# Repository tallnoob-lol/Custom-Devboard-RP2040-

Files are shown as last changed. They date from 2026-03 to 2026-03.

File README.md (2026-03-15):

# Custom-Devboard-RP2040-
Custom development board using the RP2040 microcontroller with 20 GPIO pins, 4 ADC pins, 2 user-controlled LED, 1 user button, etc.

## Why this?
I started this project, because I wanted to learn more about KiCAD. Also, I wanted a DevBoard that i could easily prototype with. As, most of the DevBoards online had some quirks like random GPIO arrangement or doesnt have any means of displaying a output on the board itself. So, I built this and it really helped in many ways.

## Features
- RP2040 microcontroller at 133MHz
- USB Type-C connector
- max 600mA power draw
- Boot and reset buttons
- Power & 2 User LED
- GPIO header pins
- Debug connector
- Bootsel, Reset & User Buttons

## Hardware Design
The hardware design will include:
- Power by AP2112K-3.3 linear LDO regulator
- 16mB External QSPI flash from W25Q16JVZPIQ TR
- USB-C interface for programming and power
- Clock source: 12MHz Crystal

## Pictures
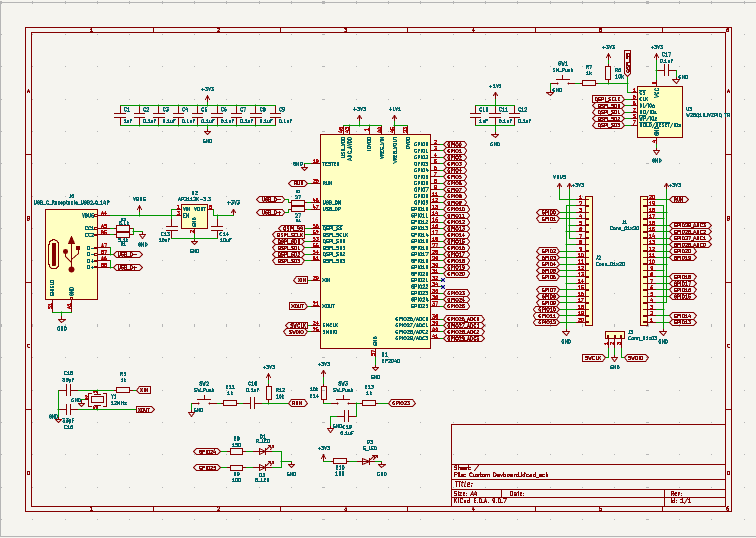
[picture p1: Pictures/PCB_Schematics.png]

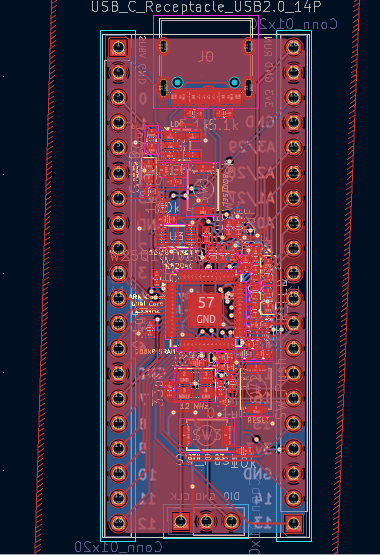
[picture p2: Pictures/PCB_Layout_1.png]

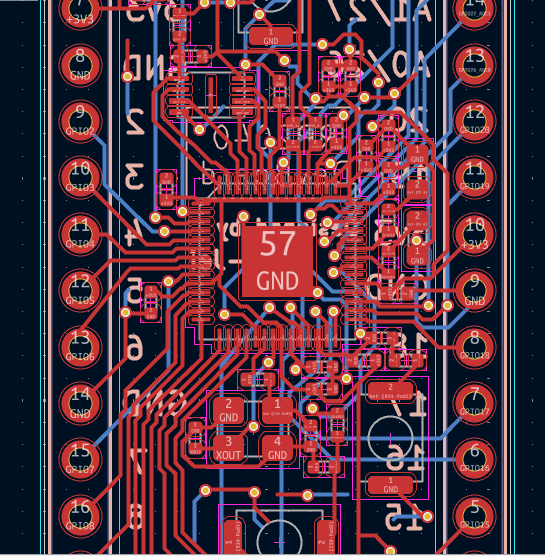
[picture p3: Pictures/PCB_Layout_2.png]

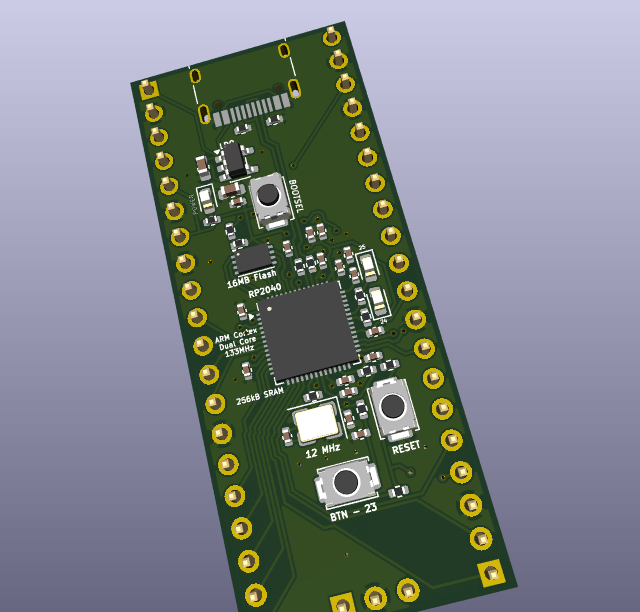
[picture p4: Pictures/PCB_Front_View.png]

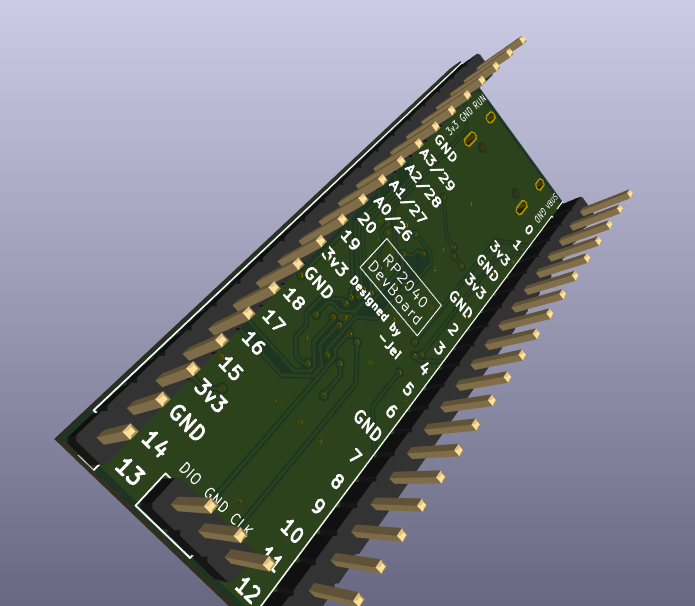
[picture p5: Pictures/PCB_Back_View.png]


## Future Improvements
- Add Li-ion compatibility
- On-Board tiny OLED display
- Improved portability for prototyping

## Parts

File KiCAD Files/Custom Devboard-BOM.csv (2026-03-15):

Id | Designator | Footprint | Quantity | Designation | Supplier and ref
1 | U3 | Winbond_USON-8-1EP_3x2mm_P0.5mm_EP0.2x1.6mm | 1 | W25Q16JVZPIQ TR
2 | R13,R5,R7,R11 | R_0402_1005Metric | 4 | 1k
3 | C10,C1 | C_0402_1005Metric | 2 | 1uF
4 | C19,C9,C6,C17,C12,C11,C18,C2,C5,C4,C7,C8,C3 | C_0402_1005Metric | 13 | 0.1uF
5 | U2 | SOT-23-5 | 1 | AP2112K-3.3
6 | D1 | LED_0603_1608Metric | 1 | R_LED
7 | U1 | QFN-56-1EP_7x7mm_P0.4mm_EP3.2x3.2mm | 1 | RP2040
8 | C15,C16 | C_0402_1005Metric | 2 | 33pF
9 | Y1 | Crystal_SMD_3225-4Pin_3.2x2.5mm | 1 | 12MHz
10 | R1,R2 | R_0402_1005Metric | 2 | 5.1k
11 | D3 | LED_0603_1608Metric | 1 | G_LED
12 | R4,R3 | R_0402_1005Metric | 2 | 27
13 | R14,R6,R12 | R_0402_1005Metric | 3 | 10k
14 | D2 | LED_0603_1608Metric | 1 | B_LED
15 | SW3,SW1,SW2 | SW_Push_SPST_NO_Alps_SKRK | 3 | SW_Push
16 | C13,C14 | C_0603_1608Metric | 2 | 10uF
17 | R9,R10 | R_0402_1005Metric | 2 | 100
18 | R8 | R_0402_1005Metric | 1 | 150
19 | J0 | USB_C_Receptacle_HRO_TYPE-C-31-M-12 | 1 | USB_C_Receptacle_USB2.0_14P
20 | J2,J1 | PinHeader_1x20_P2.54mm_Vertical | 2 | Conn_01x20
21 | J3 | PinHeader_1x03_P2.54mm_Vertical | 1 | Conn_01x03

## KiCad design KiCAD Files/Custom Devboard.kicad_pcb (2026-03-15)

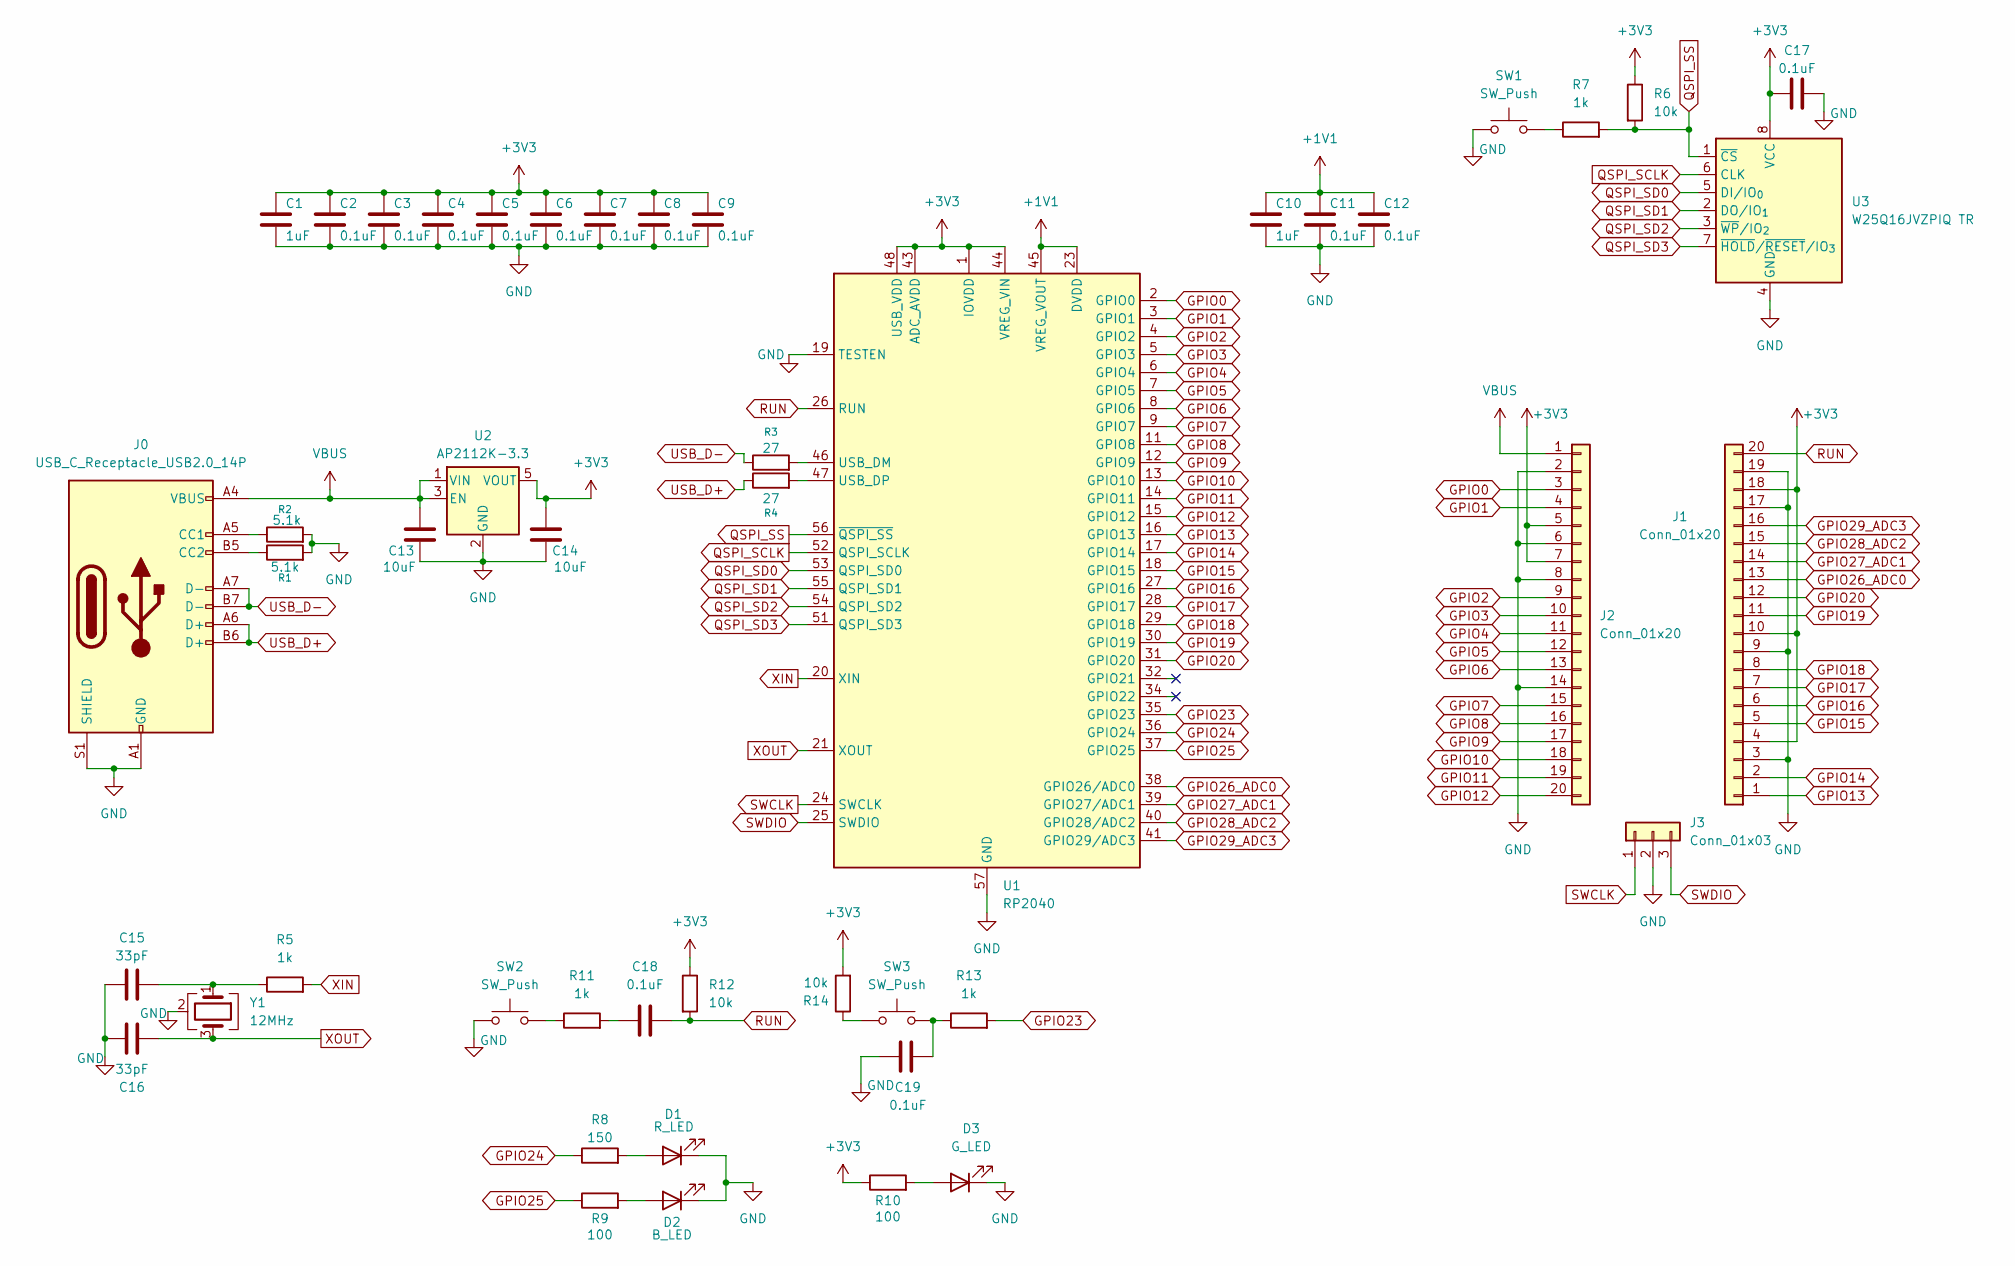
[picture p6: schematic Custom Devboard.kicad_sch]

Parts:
C1, C10: 1uF; C_0402_1005Metric
C2, C3, C4, C5, C6, C7, C8, C9, C11, C12, C17, C18, C19: 0.1uF; C_0402_1005Metric
C13, C14: 10uF; C_0603_1608Metric
C15, C16: 33pF; C_0402_1005Metric
D1: R_LED; LED_0603_1608Metric
D2: B_LED; LED_0603_1608Metric
D3: G_LED; LED_0603_1608Metric
J0: USB_C_Receptacle_USB2.0_14P; USB_C_Receptacle_HRO_TYPE-C-31-M-12
J1, J2: Conn_01x20; PinHeader_1x20_P2.54mm_Vertical
J3: Conn_01x03; PinHeader_1x03_P2.54mm_Vertical
R1, R2: 5.1k; R_0402_1005Metric
R3, R4: 27; R_0402_1005Metric
R5, R7, R11, R13: 1k; R_0402_1005Metric
R6, R12, R14: 10k; R_0402_1005Metric
R8: 150; R_0402_1005Metric
R9, R10: 100; R_0402_1005Metric
SW1, SW2, SW3: SW_Push; SW_Push_SPST_NO_Alps_SKRK
U1: RP2040; QFN-56-1EP_7x7mm_P0.4mm_EP3.2x3.2mm
U2: AP2112K-3.3; SOT-23-5
U3: W25Q16JVZPIQ TR; Winbond_USON-8-1EP_3x2mm_P0.5mm_EP0.2x1.6mm
Y1: 12MHz; Crystal_SMD_3225-4Pin_3.2x2.5mm

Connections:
+1V1: C10.1, C11.1, C12.1, U1.23 (DVDD), U1.45 (VREG_VOUT), U1.50 (DVDD)
+3V3: C1.1, C2.1, C3.1, C4.1, C5.1, C6.1, C7.1, C8.1, C9.1, C14.1, C17.1, J1.4, J1.10, J1.18, J2.5, J2.7, R6.1, R10.1, R12.1, R14.2, U1.1 (IOVDD), U1.10 (IOVDD), U1.22 (IOVDD), U1.33 (IOVDD), U1.42 (IOVDD), U1.43 (ADC_AVDD), U1.44 (VREG_VIN), U1.48 (USB_VDD), U1.49 (IOVDD), U2.5 (VOUT), U3.8 (VCC)
GND: C1.2, C2.2, C3.2, C4.2, C5.2, C6.2, C7.2, C8.2, C9.2, C10.2, C11.2, C12.2, C13.2, C14.2, C15.1, C16.1, C17.2, C19.1, D1.1 (K), D2.1 (K), D3.1 (K), J0.A1 (GND), J0.A12 (GND), J0.B1 (GND), J0.B12 (GND), J0.S1 (SHIELD), J1.3, J1.9, J1.17, J1.19, J2.2, J2.6, J2.8, J2.14, J3.2, R1.2, R2.2, SW1.1, SW2.1, U1.19 (TESTEN), U1.57 (GND), U2.2 (GND), U3.4 (GND), Y1.2 (G), Y1.4 (G)
GPIO0: J2.3, U1.2 (GPIO0)
GPIO1: J2.4, U1.3 (GPIO1)
GPIO2: J2.9, U1.4 (GPIO2)
GPIO3: J2.10, U1.5 (GPIO3)
GPIO4: J2.11, U1.6 (GPIO4)
GPIO5: J2.12, U1.7 (GPIO5)
GPIO6: J2.13, U1.8 (GPIO6)
GPIO7: J2.15, U1.9 (GPIO7)
GPIO8: J2.16, U1.11 (GPIO8)
GPIO9: J2.17, U1.12 (GPIO9)
GPIO10: J2.18, U1.13 (GPIO10)
GPIO11: J2.19, U1.14 (GPIO11)
GPIO12: J2.20, U1.15 (GPIO12)
GPIO13: J1.1, U1.16 (GPIO13)
GPIO14: J1.2, U1.17 (GPIO14)
GPIO15: J1.5, U1.18 (GPIO15)
GPIO16: J1.6, U1.27 (GPIO16)
GPIO17: J1.7, U1.28 (GPIO17)
GPIO18: J1.8, U1.29 (GPIO18)
GPIO19: J1.11, U1.30 (GPIO19)
GPIO20: J1.12, U1.31 (GPIO20)
GPIO23: R13.2, U1.35 (GPIO23)
GPIO24: R8.1, U1.36 (GPIO24)
GPIO25: R9.1, U1.37 (GPIO25)
GPIO26_ADC0: J1.13, U1.38 (GPIO26/ADC0)
GPIO27_ADC1: J1.14, U1.39 (GPIO27/ADC1)
GPIO28_ADC2: J1.15, U1.40 (GPIO28/ADC2)
GPIO29_ADC3: J1.16, U1.41 (GPIO29/ADC3)
unnamed: C15.2, R5.1, Y1.1
unnamed: C18.1, R11.2
unnamed: C19.2, R13.1, SW3.2
unnamed: D1.2 (A), R8.2
unnamed: D2.2 (A), R9.2
unnamed: D3.2 (A), R10.2
unnamed: J0.A5 (CC1), R2.1
unnamed: J0.B5 (CC2), R1.1
unnamed: R7.1, SW1.2
unnamed: R11.1, SW2.2
unnamed: R14.1, SW3.1
unnamed: R3.2, U1.46 (USB_DM)
unnamed: R4.2, U1.47 (USB_DP)
QSPI_SCLK: U1.52 (QSPI_SCLK), U3.6 (CLK)
QSPI_SD0: U1.53 (QSPI_SD0), U3.5 (DI/IO_{0})
QSPI_SD1: U1.55 (QSPI_SD1), U3.2 (DO/IO_{1})
QSPI_SD2: U1.54 (QSPI_SD2), U3.3 (~WP/IO_{2})
QSPI_SD3: U1.51 (QSPI_SD3), U3.7 (~HOLD/~RESET/IO_{3})
QSPI_SS: R6.2, R7.2, U1.56 (~QSPI_SS), U3.1 (~CS)
RUN: C18.2, J1.20, R12.2, U1.26 (RUN)
SWCLK: J3.1, U1.24 (SWCLK)
SWDIO: J3.3, U1.25 (SWDIO)
USB_D+: J0.A6 (D+), J0.B6 (D+), R4.1
USB_D-: J0.A7 (D-), J0.B7 (D-), R3.1
VBUS: C13.1, J0.A4 (VBUS), J0.A9 (VBUS), J0.B4 (VBUS), J0.B9 (VBUS), J2.1, U2.1 (VIN), U2.3 (EN)
XIN: R5.2, U1.20 (XIN)
XOUT: C16.2, U1.21 (XOUT), Y1.3

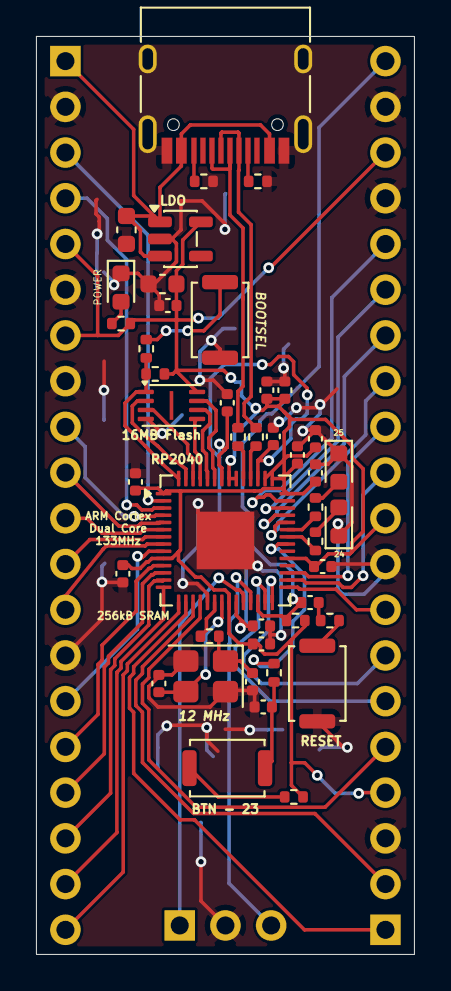
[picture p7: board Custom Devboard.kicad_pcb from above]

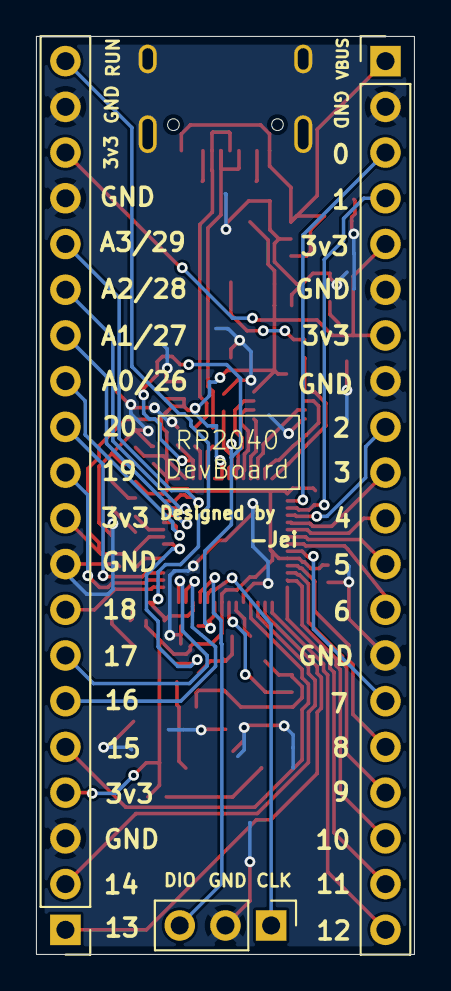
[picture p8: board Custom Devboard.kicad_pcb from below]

Board: 2 copper layers, 21.0 x 51.0 mm, 47 parts (3 on the bottom side), 58 nets.

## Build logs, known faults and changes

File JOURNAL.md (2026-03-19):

<!--
  This journal is auto generated by Stasis.
-->

# 3/15/2026 9 AM - Final Review and BOM

_Time spent: 1.5h_

Today, I solved last few of the errors shown by the DRC, like thermal releif spoke, etc and addressed the warning shown and corrected them.


 Finally, I was able to design the silkscreen with relief. Added texts to show specs of the SoC and some useful text like, the GPIO number of the LED/button is connected to, etc. Added texts to show GPIO number of each header pin, and stamped my name on it. I also switched the pin headers from front-facing to back-facing.




I had finally completed a fully working model of my custom DevBoard. I extracted the PCB fabrication files and uploaded it to GitHub.

Felt like, I had took a very hard endeavour to begin with my learning of KiCAD. But at last, it felt like it was worth the effort, and I had learned more than enough to gain confidence to develop my own DevBoard or a complex circuit without much external help/guidance.

Uploaded my files to JLCPCB website to see cost, and other variable. Found that PCBA was expensive, more expensive than buying soldering equipment and soldering mself.


So, I decided to learn the skill of soldering by buying the required equipment and parts and soldering the DevBoard myself.






# 3/15/2026 9 AM - PCB Designing

_Time spent: 3.5h_

Again, followed the tutorial, for header, SoC and placement of other major stuff. Also learnt how to define the size of PCB in edge.Cuts layer.

Now came the tough part, had to place individual capacitors and resistors perfectly, especially the decoupling capacitors, in such tight space. Placed with a bit of allowance space for traces.


But laying out the traces was really the time-consuming part. I had mistakenly used the default PCB setting, which had a high trace clearance setting, making my layout harder and messy. I asked AI for suggestion and corrected the issue. Thought of using a 4 Layer, but decided to keep with 2 Layer as a challenge to myself.

Finally, finished connecting all pins, except the ground pins as said by the tutorial. It did look a bit tightly packed and messier than the picture shown on tutorial, but it worked and all the traces followed the rules mentioned.





Now, had to lay the copper ground plane, which i felt initially was the easiest part, but became worse due to a simple mistake. Again I had large clearance for the zone to trace and many other setting, which made copper tracing so difficult. I hadn't recognized this mistake at first and made the PCB more worse.
Many planes were just isolated islands and ground pads of many were not connected. So I had to individually connect pads and islands together. It became so tight, i had to do a large roundabout or multiple via's just to reach another nearby pad.

I finally figured and solved the issue of large clearance, when DRC show 100+ errors. I took a screenshot and asked AI, which helped resolve the problem.





# 3/15/2026 9 AM - Research and Schematics

_Time spent: 5.25h_

I started researching about the chip, I was going to develop the board from, the RP2040. Also skimmed the project tutorial.

I followed the tutorial as it said drawing the schematics of the DevBoard, while researching in-depth about the reason about why the tutorial did something (like added a decoupling capacitor, their purpose, what is SPI, etc).



I learnt a lot about KiCAD software, from placing a basic footprint to tuning skew of differential pairs, and also came to know the rule of traces, like the USB data differential pair and to avoid 90-degree turns of traces.

It was a smooth going, following the tutorial, asking doubts to AI, learning functions about the software, I didn't know about.


When the tutorial finished their schematic part, I wanted to add some features myself, so I added a LED to indicate power, a reset button, a user button, and 2 LED connected to 2 unused GPIO pin. ALL of that were easy except the user button, which I decided to implement a hardware debounce.

Finally, finished the schematics fully by 5-hour mark, without much errors, which can be ignored or easily solved.

Opened the PCB editor and imported all the footprints from the schematic, and ended the session.




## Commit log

2026-03-15 Rename Screenshot 2026-03-14 170258.png to PCB Front View
2026-03-15 Rename Screenshot 2026-03-14 170306.png to PCB Back View
2026-03-15 Rename Screenshot 2026-03-15 162513.png to PCB Schematics
2026-03-15 Rename Screenshot 2026-03-15 162536.png to PCB Layout - 1
2026-03-15 Rename Screenshot 2026-03-15 162616.png to PCB Layout - 2
2026-03-15 Rename PCB Back View to PCB Back View.png
2026-03-15 Rename PCB Front View to PCB Front View.png
2026-03-15 Rename PCB Layout - 1 to PCB Layout 1.png
2026-03-15 Rename PCB Layout - 2 to PCB Layout 2.png
2026-03-15 Rename PCB Schematics to PCB Schematics.png
2026-03-15 Rename PCB Schematics.png to PCB_Schematics.png
2026-03-15 Rename PCB Back View.png to PCB_Back_View.png
2026-03-15 Rename PCB Front View.png to PCB_Front_View.png
2026-03-15 Rename PCB Layout 1.png to PCB_Layout_1.png
2026-03-15 Rename PCB Layout 2.png to PCB_Layout_2.png
2026-03-15 Rename Custom Devboard-all-pos.csv to KiCAD Files/Custom Devboard-all-pos.csv
    [Custom Devboard-all-pos.csv]
2026-03-15 Rename Custom Devboard.csv to KiCAD Files/Custom Devboard-BOM.csv
    [Custom Devboard-BOM.csv]
